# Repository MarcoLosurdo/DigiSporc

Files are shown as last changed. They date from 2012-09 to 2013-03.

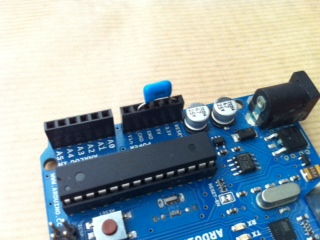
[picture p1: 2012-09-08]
pic/capacitor_ResetGND.jpeg

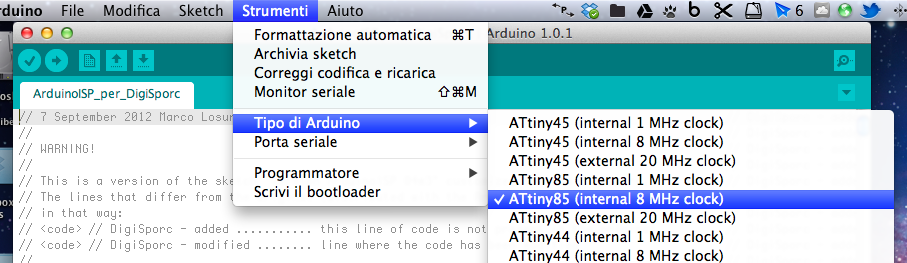
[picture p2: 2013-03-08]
pic/ATtiny-Boards-Menu.png

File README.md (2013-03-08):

# DigiSporc

> The simple and cheap parody of Digispark

Il Purcello!!!

DigiSporc is a mini single-board microcontroller for ATtiny25/45/85 family that is **really easy to program and use** thanks to the application of a simple idea:

*its connector, plugged in the first female strip connector  of an Arduino Uno or Duemilanove (from the AREF to the digital port 8), has the pin already arranged in the right sequence to be able to be programmed with an Arduino in ISP mode.*

## 1.Intro
A few weeks ago, on Kickstarter, I saw a very interesting project called [Digispark](http://www.kickstarter.com/projects/digistump/digispark-the-tiny-arduino-enabled-usb-dev-board).

> Digispark - The micro-sized, Arduino enabled, usb development board

I'm not an electronic engineer, I just know a bit as the Arduino boards (and clones) works, so the first question I did was: «All the Arduino needs an FTDI chip; how is possible to program an ATtiny directly through a USB?».   
It seems that the "magic" happens thanks to a special bootloader and a data transmission technique called [bitbanging](http://en.wikipedia.org/wiki/Bit_banging). All this at the beginning it seemed very cool... but too unnecessarily complicated for someone like me who barely knows the difference between a LED and a capacitor.

Then, I remembered a [simple tutorial](http://hlt.media.mit.edu/?p=1695) published by the _MIT media lab_ about ATtiny programming using an Arduino. Giving it a further look I noticed that all pins required to program an ATtiny were on the strip connector Arduino that goes from AREF to digital 8, furthermore, the pins of a ATtiny are exactly eight as on that strip.  
So I came up with an idea: **why don't build an ATtiny45/85 board that can be plugged into an Arduino connector?**

Nothing could be easier! Et voilà:

Proto boards

That pic shows two prototypes (with and without the reset button). Into the repository you can find both named **DigiSporc** and **DigiSporc_Nano** (yes, I'm a sarcastic Apple fanboy).  
The prototype of DigiSporc in that pic, however, has no voltage regulator.

### 1.1.ATtiny and DigiSpork Pin-Outs



## 2.Getting Started
This is the DigiSporc Nano ([schematics](https://raw.github.com/MarcoLosurdo/DigiSporc/master/DigiSporc_nano.png)):  
  
and all you need to build it is:

### 2.1.Hardware
* 1x 10K resistor (brown, black, orange, gold)
* 1x 1K resistor (brown, black, red, gold)
* 2x 0.1uF capacitors (but just one of them will be welded on the board, I promise!)
* 1x ATtiny85 (or 45)
* 1x 3mm LED
* 1x 1x8 pin headers (90° or straight)
* 1x 8x8 matrix board (but also an 8x6 is enough)

Componenti

It is always better to avoid solder directly to a microcontroller, and I prefer to use two 1x4 female pin header instead a socket.
Into the schematic there is a place for another 1x2 female pin but you'll need it if you plan to use the original version of ArduinoISP.

This tutorial was written by an Italian, so do not expect too many details (much less a perfect grammar). I'm not lazy, just don't wanna offend your intelligence: it is obvious that in order to complete the project you will need a **soldering iron**, some **tin wire**, an **Arduino** (Duemilanove or Uno) and an **USB cable** too. 
 
If you have no idea how to read a schematic or to make a circuit on a matrix board: search on Google. The internet is full of tinkering tutorials and I do not want to add another one.
 
...Ok, I'm lazy. Do your best, I trust you!

### 2.2.Software
* [Arduino IDE](http://arduino.cc/en/Main/Software).
* My version of [ArduinoISP](https://raw.github.com/MarcoLosurdo/DigiSporc/master/ArduinoISP_per_DigiSporc.ino)
* [ATtiny hardware support](https://github.com/damellis/attiny/archive/master.zip)

#### 2.2.1.Installing ATtiny support in 37 easy steps:
1. Locate your Arduino sketchbook folder (start **Arduino IDE** and watch in the preferences);
1. if non exists, create a new sub-folder **hardware** in the sketchbook folder;
1. copy the attiny folder from inside the .zip to the **hardware** folder (you should obtain a structure like _Documents/Arduino/hardware/attiny_ that contains the file **boards.txt** and another folder called variants);
1. restart the Arduino IDE;
1. you should see ATtiny entries in the _Tools > Board_ menu;
1. the steps are just 5, not 37. I was joking. Move on.

### 2.3.ATtiny setup
1. Connect and select your Arduino from _Tools > Boards_ menu (e.g. **Arduino Uno**) and the right serial port (if you have a problem already at this step, please refer to the [official Arduino IDE guide](http://arduino.cc/en/Guide/HomePage));
1. connect and upload [ArduinoISP per DigiSporc](https://raw.github.com/MarcoLosurdo/DigiSporc/master/ArduinoISP_per_DigiSporc.ino) onto your Arduino board;
1. select your DigiSporc microcontroller from the _Tools > Boards_ menu (e.g. **ATtiny85 8 MHz**);
Menu with ATtiny

1. Select **Arduino as ISP** from the _Tools > Programmer_ menu;  


1. plug a 0.1uF **ceramic** capacitor between Arduino's RESET and GND (sometimes it is unnecessary, but it is always better to do);  
  
You can also use a electrolytic capacitor (10uF), but you have to make sure to plug the negative pin of capacitor (shorter and marked with a black stripe on the case of the capacitor) onto GND.

1. plug your DigiSporc into the AREF–DIGITAL8 slot;  

1. run the **Burn Bootloader** command from the Tools menu.  


You need to do this **once** for every ATtiny.  
This doesn’t burn a bootloader onto the ATtiny, just configures the fuse bits of the microcontroller so it runs at 8 MHz.

### 2.4.Programming the DigiSporc for the first time
If you've restarted the Arduino IDE or changed something, repeat the steps from 1 to 6 as above for the ATtiny setup, then:

1. Open the **Blink** sketch from the _File > Examples > Basics_ menu;
1. edit the sketch and change the pin numbers from 13 to 0;  
`int led = 13;` → `int led = 0;`
1. upload the sketch and enjoy your blinking LED (if the LED don't blinks, something gone wrong).

## 3.Notes
* On the Arduino used as ISP programmer, still possible to run  the original version (supplied with the Arduino IDE) of **Arduino ISP**. But will be necessary to manually perform the connection between the 5V pin of Arduino and DigiSporc to provide the power supply;
* DigiSporc footprint it's 36,84% (175mm^2) less than the best competitor:
 
* OK, the DigiSpark seems to have 6 I/O pin and Digisporc just 5. But remember: less is more! :-?
* **sporc** it's the abbreviation of the italian word "sporco" (dirty).
* **I want to clarify explicitly**: The fact that the DigiSporc really works, does not mean that this is a serious project. I just wanted to do something to practice in the use of Github, EagleCad, Markdown and teasing (just a little) who use Kickstarter to raise money for projects that, in reality, are nothing more than other open source projects combined toghether.

## 4.Credits
- The project is based on the tutorial [Programming an ATtiny w/ Arduino 1.0.1](http://hlt.media.mit.edu/?p=1695) by MIT media lab.
- Many thanks to the people of [Tokyo Hackerspace](http://tokyohackerspace.org/) for any advices, but especially for the unexpected enthusiasm with which they welcomed the project.
- I’m sorry not to be able to thank guys DigiSpark, but at the time of publication of my project on Github, they had not yet published nothing of their "open hardware" board… probably, they were too busy to collect their quarter of a million dollars on KickStarter :D #LOL

## 5.Licence
DigiSporc (c) 2012, Marco Losurdo  
This project is realeased under the [CC-BY-SA 3.0](http://creativecommons.org/licenses/by-sa/3.0/us/) License.

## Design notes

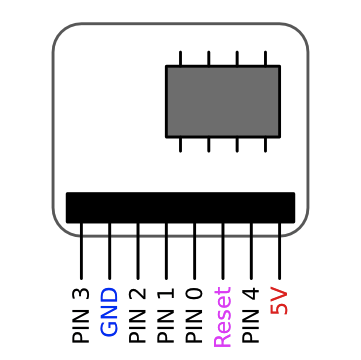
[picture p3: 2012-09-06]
pic/DigiSporc_pinout.png

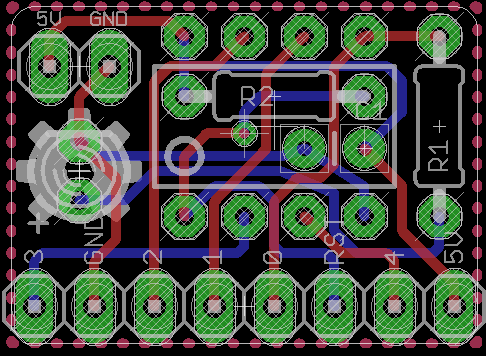
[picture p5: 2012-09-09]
DigiSporc_nano-board.png

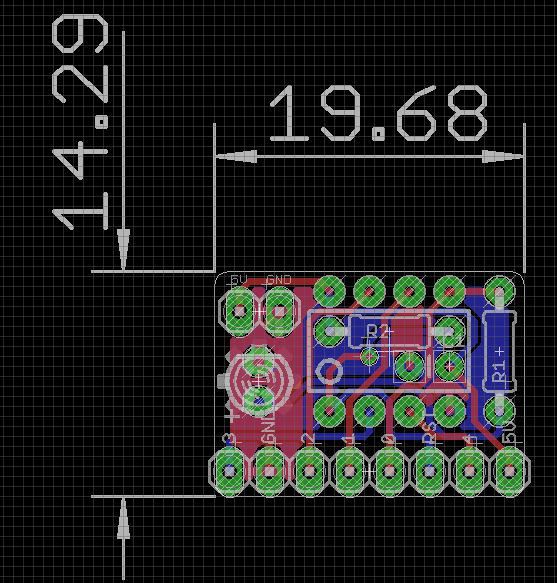
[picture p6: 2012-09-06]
pic/DigiSporc_nano.png

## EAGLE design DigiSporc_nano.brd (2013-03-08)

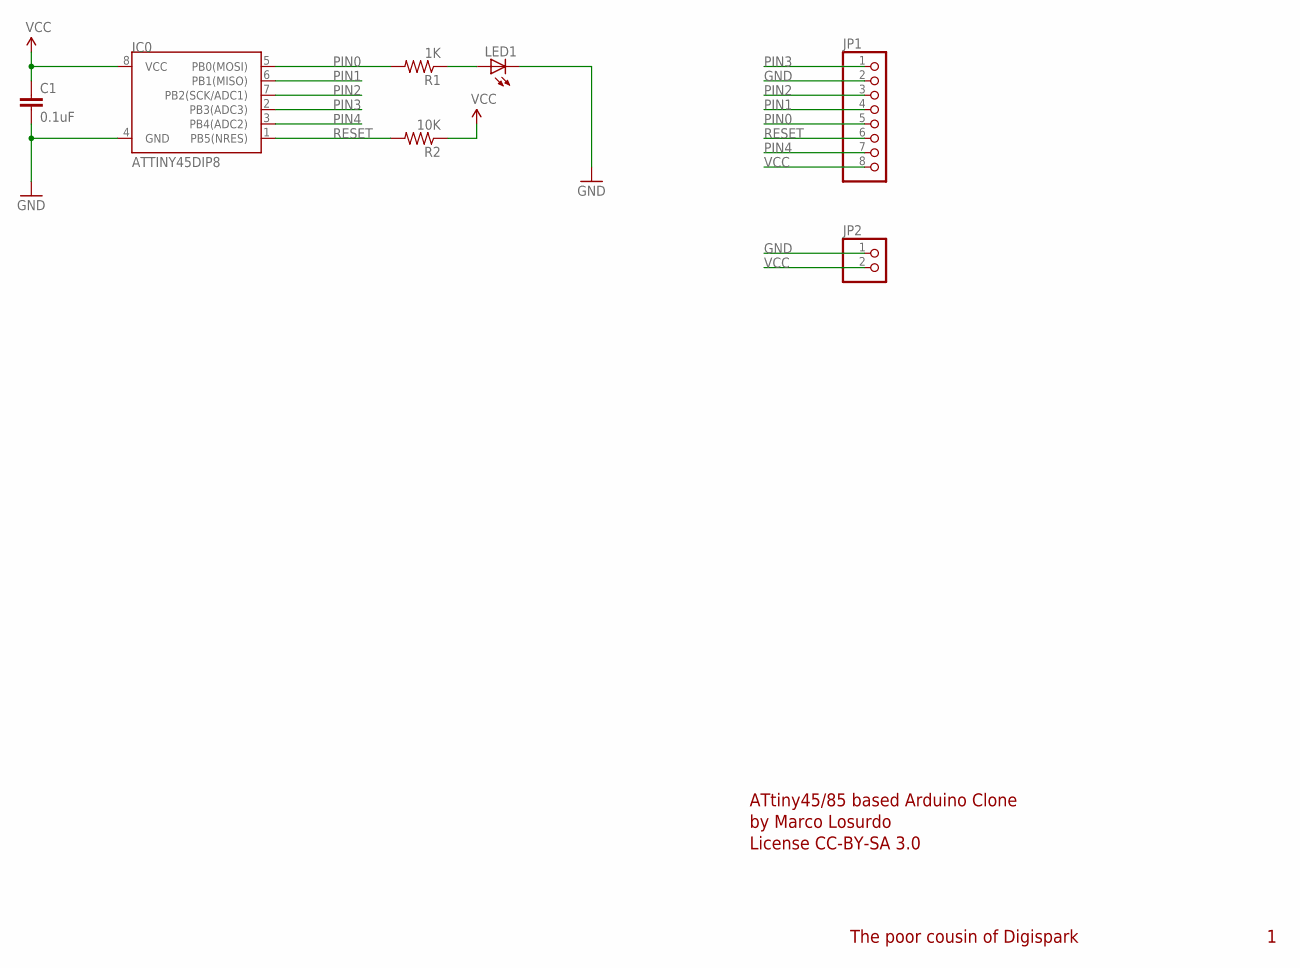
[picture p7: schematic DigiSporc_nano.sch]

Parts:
C1: 0.1uF; CAP-PTH-SMALL
IC0: ATTINY45DIP8; DIP08
JP1: PINHD-1X8; 1X08
JP2: PINHD-1X2; 1X02
LED1: LED3MM
R1: 1K; 0204/7
R2: 10K; 0204/7

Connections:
GND: C1.2, IC0.4 (GND), JP1.2, JP2.1, LED1.K (C)
unnamed: LED1.A, R1.1
PIN0: IC0.5 (PB0(MOSI)), JP1.5, R1.2
PIN1: IC0.6 (PB1(MISO)), JP1.4
PIN2: IC0.7 (PB2(SCK/ADC1)), JP1.3
PIN3: IC0.2 (PB3(ADC3)), JP1.1
PIN4: IC0.3 (PB4(ADC2)), JP1.7
RESET: IC0.1 (PB5(NRES)), JP1.6, R2.2
VCC: C1.1, IC0.8 (VCC), JP1.8, JP2.2, R2.1

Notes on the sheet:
ATtiny45/85 based Arduino Clone
by Marco Losurdo
License CC-BY-SA 3.0
The poor cousin of Digispark

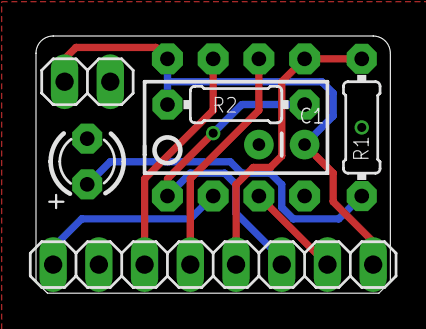
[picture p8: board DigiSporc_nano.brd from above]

Board: 2 copper layers, 19.7 x 14.3 mm, 8 parts (1 on the bottom side), 9 nets.

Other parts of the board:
U$1: OSHWLOGO_TOL_0.2

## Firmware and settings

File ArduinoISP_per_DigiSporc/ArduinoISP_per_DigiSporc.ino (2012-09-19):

// 7 September 2012 Marco Losurdo                                                                    // DigiSporc - added
//                                                                                                   // DigiSporc - added
// WARNING!                                                                                          // DigiSporc - added
//                                                                                                   // DigiSporc - added
// This is a version of the sketch "version ArduinoISP 04m3" customized for the DigiSporc.           // DigiSporc - added
// The lines that differ from the original (distributed with the Arduino IDE) are commented out      // DigiSporc - added
// in that way:                                                                                      // DigiSporc - added
// <code> // DigiSporc - added ........... this line of code is not present in the original          // DigiSporc - added
// <code> // DigiSporc - modified ........ line where the code has been modified                     // DigiSporc - added
//                                                                                                   // DigiSporc - added
// The original code starts under this line.                                                         // DigiSporc - added


// ArduinoISP version 04m3
// Copyright (c) 2008-2011 Randall Bohn
// If you require a license, see 
//     http://www.opensource.org/licenses/bsd-license.php
//
// This sketch turns the Arduino into a AVRISP
// using the following arduino pins:
//
// pin name:    not-mega:         mega(1280 and 2560)
// slave reset: 10:               53 
// MOSI:        11:               51 
// MISO:        12:               50 
// SCK:         13:               52 
//
// Put an LED (with resistor) on the following pins:
// 5: Heartbeat   - shows the programmer is running                                      // DigiSporc - modified
// 6: Error       - Lights up if something goes wrong (use red if that makes sense)      // DigiSporc - modified
// 7: Programming - In communication with the slave
//
// 23 July 2011 Randall Bohn
// -Address Arduino issue 509 :: Portability of ArduinoISP
// http://code.google.com/p/arduino/issues/detail?id=509
//
// October 2010 by Randall Bohn
// - Write to EEPROM > 256 bytes
// - Better use of LEDs:
// -- Flash LED_PMODE on each flash commit
// -- Flash LED_PMODE while writing EEPROM (both give visual feedback of writing progress)
// - Light LED_ERR whenever we hit a STK_NOSYNC. Turn it off when back in sync.
// - Use pins_arduino.h (should also work on Arduino Mega)
//
// October 2009 by David A. Mellis
// - Added support for the read signature command
// 
// February 2009 by Randall Bohn
// - Added support for writing to EEPROM (what took so long?)
// Windows users should consider WinAVR's avrdude instead of the
// avrdude included with Arduino software.
//
// January 2008 by Randall Bohn
// - Thanks to Amplificar for helping me with the STK500 protocol
// - The AVRISP/STK500 (mk I) protocol is used in the arduino bootloader
// - The SPI functions herein were developed for the AVR910_ARD programmer 
// - More information at http://code.google.com/p/mega-isp

#include "pins_arduino.h"
#define RESET     SS

#define LED_HB    5        // DigiSporc - modified
#define LED_ERR   6        // DigiSporc - modified
#define LED_PMODE 7
#define PROG_FLICKER true

#define HWVER 2
#define SWMAJ 1
#define SWMIN 18

#define VOLT5 8            // DigiSporc - added


// STK Definitions
#define STK_OK      0x10
#define STK_FAILED  0x11
#define STK_UNKNOWN 0x12
#define STK_INSYNC  0x14
#define STK_NOSYNC  0x15
#define CRC_EOP     0x20 //ok it is a space...

void pulse(int pin, int times);

void setup() {
  Serial.begin(19200);
  pinMode(LED_PMODE, OUTPUT);
  pulse(LED_PMODE, 2);
  pinMode(LED_ERR, OUTPUT);
  pulse(LED_ERR, 2);
  pinMode(LED_HB, OUTPUT);
  pulse(LED_HB, 2);
  
  pinMode(VOLT5, OUTPUT);       // DigiSporc - added
  digitalWrite(VOLT5, HIGH);    // DigiSporc - added
}

int error=0;
int pmode=0;
// address for reading and writing, set by 'U' command
int here;
uint8_t buff[256]; // global block storage

#define beget16(addr) (*addr * 256 + *(addr+1) )
typedef struct param {
  uint8_t devicecode;
  uint8_t revision;
  uint8_t progtype;
  uint8_t parmode;
  uint8_t polling;
  uint8_t selftimed;
  uint8_t lockbytes;
  uint8_t fusebytes;
  int flashpoll;
  int eeprompoll;
  int pagesize;
  int eepromsize;
  int flashsize;
} 
parameter;

parameter param;

// this provides a heartbeat on pin 9, so you can tell the software is running.
uint8_t hbval=128;
int8_t hbdelta=2;
void heartbeat() {
  if (hbval > 240) hbdelta = -2;
  if (hbval < 20)  hbdelta =  2;
  hbval += hbdelta;
  analogWrite(LED_HB, hbval);
  delay(25);
}


void loop(void) {
  // is pmode active?
  if (pmode) digitalWrite(LED_PMODE, HIGH); 
  else digitalWrite(LED_PMODE, LOW);
  // is there an error?
  if (error) digitalWrite(LED_ERR, HIGH); 
  else digitalWrite(LED_ERR, LOW);

  // light the heartbeat LED
  heartbeat();
  if (Serial.available()) {
    avrisp();
  }
}

uint8_t getch() {
  while(!Serial.available());
  return Serial.read();
}
void fill(int n) {
  for (int x = 0; x < n; x++) {
    buff[x] = getch();
  }
}

#define PTIME 30
void pulse(int pin, int times) {
  do {
    digitalWrite(pin, HIGH);
    delay(PTIME);
    digitalWrite(pin, LOW);
    delay(PTIME);
  } 
  while (times--);
}

void prog_lamp(int state) {
  if (PROG_FLICKER)
    digitalWrite(LED_PMODE, state);
}

void spi_init() {
  uint8_t x;
  SPCR = 0x53;
  x=SPSR;
  x=SPDR;
}

void spi_wait() {
  do {
  } 
  while (!(SPSR & (1 << SPIF)));
}

uint8_t spi_send(uint8_t b) {
  uint8_t reply;
  SPDR=b;
  spi_wait();
  reply = SPDR;
  return reply;
}

uint8_t spi_transaction(uint8_t a, uint8_t b, uint8_t c, uint8_t d) {
  uint8_t n;
  spi_send(a); 
  n=spi_send(b);
  //if (n != a) error = -1;
  n=spi_send(c);
  return spi_send(d);
}

void empty_reply() {
  if (CRC_EOP == getch()) {
    Serial.print((char)STK_INSYNC);
    Serial.print((char)STK_OK);
  } 
  else {
    error++;
    Serial.print((char)STK_NOSYNC);
  }
}

void breply(uint8_t b) {
  if (CRC_EOP == getch()) {
    Serial.print((char)STK_INSYNC);
    Serial.print((char)b);
    Serial.print((char)STK_OK);
  } 
  else {
    error++;
    Serial.print((char)STK_NOSYNC);
  }
}

void get_version(uint8_t c) {
  switch(c) {
  case 0x80:
    breply(HWVER);
    break;
  case 0x81:
    breply(SWMAJ);
    break;
  case 0x82:
    breply(SWMIN);
    break;
  case 0x93:
    breply('S'); // serial programmer
    break;
  default:
    breply(0);
  }
}

void set_parameters() {
  // call this after reading paramter packet into buff[]
  param.devicecode = buff[0];
  param.revision   = buff[1];
  param.progtype   = buff[2];
  param.parmode    = buff[3];
  param.polling    = buff[4];
  param.selftimed  = buff[5];
  param.lockbytes  = buff[6];
  param.fusebytes  = buff[7];
  param.flashpoll  = buff[8]; 
  // ignore buff[9] (= buff[8])
  // following are 16 bits (big endian)
  param.eeprompoll = beget16(&buff[10]);
  param.pagesize   = beget16(&buff[12]);
  param.eepromsize = beget16(&buff[14]);

  // 32 bits flashsize (big endian)
  param.flashsize = buff[16] * 0x01000000
    + buff[17] * 0x00010000
    + buff[18] * 0x00000100
    + buff[19];

}

void start_pmode() {
  spi_init();
  // following delays may not work on all targets...
  pinMode(RESET, OUTPUT);
  digitalWrite(RESET, HIGH);
  pinMode(SCK, OUTPUT);
  digitalWrite(SCK, LOW);
  delay(50);
  digitalWrite(RESET, LOW);
  delay(50);
  pinMode(MISO, INPUT);
  pinMode(MOSI, OUTPUT);
  spi_transaction(0xAC, 0x53, 0x00, 0x00);
  pmode = 1;
}

void end_pmode() {
  pinMode(MISO, INPUT);
  pinMode(MOSI, INPUT);
  pinMode(SCK, INPUT);
  pinMode(RESET, INPUT);
  pmode = 0;
}

void universal() {
  int w;
  uint8_t ch;

  fill(4);
  ch = spi_transaction(buff[0], buff[1], buff[2], buff[3]);
  breply(ch);
}

void flash(uint8_t hilo, int addr, uint8_t data) {
  spi_transaction(0x40+8*hilo, 
  addr>>8 & 0xFF, 
  addr & 0xFF,
  data);
}
void commit(int addr) {
  if (PROG_FLICKER) prog_lamp(LOW);
  spi_transaction(0x4C, (addr >> 8) & 0xFF, addr & 0xFF, 0);
  if (PROG_FLICKER) {
    delay(PTIME);
    prog_lamp(HIGH);
  }
}

//#define _current_page(x) (here & 0xFFFFE0)
int current_page(int addr) {
  if (param.pagesize == 32)  return here & 0xFFFFFFF0;
  if (param.pagesize == 64)  return here & 0xFFFFFFE0;
  if (param.pagesize == 128) return here & 0xFFFFFFC0;
  if (param.pagesize == 256) return here & 0xFFFFFF80;
  return here;
}


void write_flash(int length) {
  fill(length);
  if (CRC_EOP == getch()) {
    Serial.print((char) STK_INSYNC);
    Serial.print((char) write_flash_pages(length));
  } 
  else {
    error++;
    Serial.print((char) STK_NOSYNC);
  }
}

uint8_t write_flash_pages(int length) {
  int x = 0;
  int page = current_page(here);
  while (x < length) {
    if (page != current_page(here)) {
      commit(page);
      page = current_page(here);
    }
    flash(LOW, here, buff[x++]);
    flash(HIGH, here, buff[x++]);
    here++;
  }

  commit(page);

  return STK_OK;
}

#define EECHUNK (32)
uint8_t write_eeprom(int length) {
  // here is a word address, get the byte address
  int start = here * 2;
  int remaining = length;
  if (length > param.eepromsize) {
    error++;
    return STK_FAILED;
  }
  while (remaining > EECHUNK) {
    write_eeprom_chunk(start, EECHUNK);
    start += EECHUNK;
    remaining -= EECHUNK;
  }
  write_eeprom_chunk(start, remaining);
  return STK_OK;
}
// write (length) bytes, (start) is a byte address
uint8_t write_eeprom_chunk(int start, int length) {
  // this writes byte-by-byte,
  // page writing may be faster (4 bytes at a time)
  fill(length);
  prog_lamp(LOW);
  for (int x = 0; x < length; x++) {
    int addr = start+x;
    spi_transaction(0xC0, (addr>>8) & 0xFF, addr & 0xFF, buff[x]);
    delay(45);
  }
  prog_lamp(HIGH); 
  return STK_OK;
}

void program_page() {
  char result = (char) STK_FAILED;
  int length = 256 * getch();
  length += getch();
  char memtype = getch();
  // flash memory @here, (length) bytes
  if (memtype == 'F') {
    write_flash(length);
    return;
  }
  if (memtype == 'E') {
    result = (char)write_eeprom(length);
    if (CRC_EOP == getch()) {
      Serial.print((char) STK_INSYNC);
      Serial.print(result);
    } 
    else {
      error++;
      Serial.print((char) STK_NOSYNC);
    }
    return;
  }
  Serial.print((char)STK_FAILED);
  return;
}

uint8_t flash_read(uint8_t hilo, int addr) {
  return spi_transaction(0x20 + hilo * 8,
  (addr >> 8) & 0xFF,
  addr & 0xFF,
  0);
}

char flash_read_page(int length) {
  for (int x = 0; x < length; x+=2) {
    uint8_t low = flash_read(LOW, here);
    Serial.print((char) low);
    uint8_t high = flash_read(HIGH, here);
    Serial.print((char) high);
    here++;
  }
  return STK_OK;
}

char eeprom_read_page(int length) {
  // here again we have a word address
  int start = here * 2;
  for (int x = 0; x < length; x++) {
    int addr = start + x;
    uint8_t ee = spi_transaction(0xA0, (addr >> 8) & 0xFF, addr & 0xFF, 0xFF);
    Serial.print((char) ee);
  }
  return STK_OK;
}

void read_page() {
  char result = (char)STK_FAILED;
  int length = 256 * getch();
  length += getch();
  char memtype = getch();
  if (CRC_EOP != getch()) {
    error++;
    Serial.print((char) STK_NOSYNC);
    return;
  }
  Serial.print((char) STK_INSYNC);
  if (memtype == 'F') result = flash_read_page(length);
  if (memtype == 'E') result = eeprom_read_page(length);
  Serial.print(result);
  return;
}

void read_signature() {
  if (CRC_EOP != getch()) {
    error++;
    Serial.print((char) STK_NOSYNC);
    return;
  }
  Serial.print((char) STK_INSYNC);
  uint8_t high = spi_transaction(0x30, 0x00, 0x00, 0x00);
  Serial.print((char) high);
  uint8_t middle = spi_transaction(0x30, 0x00, 0x01, 0x00);
  Serial.print((char) middle);
  uint8_t low = spi_transaction(0x30, 0x00, 0x02, 0x00);
  Serial.print((char) low);
  Serial.print((char) STK_OK);
}
//////////////////////////////////////////
//////////////////////////////////////////


////////////////////////////////////
////////////////////////////////////
int avrisp() { 
  uint8_t data, low, high;
  uint8_t ch = getch();
  switch (ch) {
  case '0': // signon
    error = 0;
    empty_reply();
    break;
  case '1':
    if (getch() == CRC_EOP) {
      Serial.print((char) STK_INSYNC);
      Serial.print("AVR ISP");
      Serial.print((char) STK_OK);
    }
    break;
  case 'A':
    get_version(getch());
    break;
  case 'B':
    fill(20);
    set_parameters();
    empty_reply();
    break;
  case 'E': // extended parameters - ignore for now
    fill(5);
    empty_reply();
    break;

  case 'P':
    start_pmode();
    empty_reply();
    break;
  case 'U': // set address (word)
    here = getch();
    here += 256 * getch();
    empty_reply();
    break;

  case 0x60: //STK_PROG_FLASH
    low = getch();
    high = getch();
    empty_reply();
    break;
  case 0x61: //STK_PROG_DATA
    data = getch();
    empty_reply();
    break;

  case 0x64: //STK_PROG_PAGE
    program_page();
    break;

  case 0x74: //STK_READ_PAGE 't'
    read_page();    
    break;

  case 'V': //0x56
    universal();
    break;
  case 'Q': //0x51
    error=0;
    end_pmode();
    empty_reply();
    break;

  case 0x75: //STK_READ_SIGN 'u'
    read_signature();
    break;

    // expecting a command, not CRC_EOP
    // this is how we can get back in sync
  case CRC_EOP:
    error++;
    Serial.print((char) STK_NOSYNC);
    break;

    // anything else we will return STK_UNKNOWN
  default:
    error++;
    if (CRC_EOP == getch()) 
      Serial.print((char)STK_UNKNOWN);
    else
      Serial.print((char)STK_NOSYNC);
  }
}

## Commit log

2012-09-08 Ho aggiunto il maiale!
2012-09-09 Schematics and board in .png added
    [DigiSporc.sch, DigiSporc_nano.sch]
2012-09-19 Heartbeat parameters changed.
    Heartbeat parameters changed.
    It is just a cosmetic change for the LED blinking, that don't affect
    any practical feature.
2013-03-08 Link Update
    Aggiornato link ad hardware support per ATtiny.
    [DigiSporc_nano.brd]
